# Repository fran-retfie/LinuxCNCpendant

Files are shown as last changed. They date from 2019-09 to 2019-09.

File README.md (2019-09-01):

# LinuxCNC Pendant

This is a pendant for linuxCNC using an SparkFun SAMD21 Dev Breakout but with little or no changes to the program you can run this on other arduino UNO style board.

## Getting Started

**warning** this project may require some changes to make it work properly with your hardware

The project is divided in 4 directories:
* model - a FreeCAD project of the enclosure and a G-code for cutting it
* PCB - a kicad project of the PCB
* Arduino
* Python

### Prerequisites

I suggest you check the PCB before starting beacause there will be maybe some issues: (eg: spacings, SMD parts filipped, ecc..)

for running python program you need the following packages:
* linuxCNC
* TkInter
* tk-tools
* pyserial

### Installing

Upload arduino 'remoteCNC' project on the board and run the python 'remoteCNC' program on a PC with linuxCNC running

## Running the tests

To check pushbuttons and analog input use the 'remoteCNC_test' program on both arduino and PC side.

## Contributing

This project expecially the software in not completed so you are free to contribuite in any way you want.

## Authors

* **Francesco Osti** - *Initial work* - [fran-retfie](https://github.com/fran-retfie)

See also the list of [contributors](https://github.com/fran-retfie/LinuxCNCpendant/contributors)

## License

This project is licensed under the MIT License - see the [LICENSE.md](LICENSE.md) file for details

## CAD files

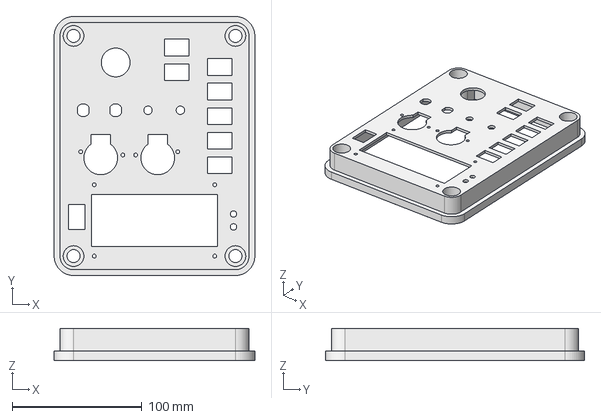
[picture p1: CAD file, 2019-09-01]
model/Test1.FCStd
155.0 x 200.0 x 25.0 mm

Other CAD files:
model/PathCoperchio.FCStd

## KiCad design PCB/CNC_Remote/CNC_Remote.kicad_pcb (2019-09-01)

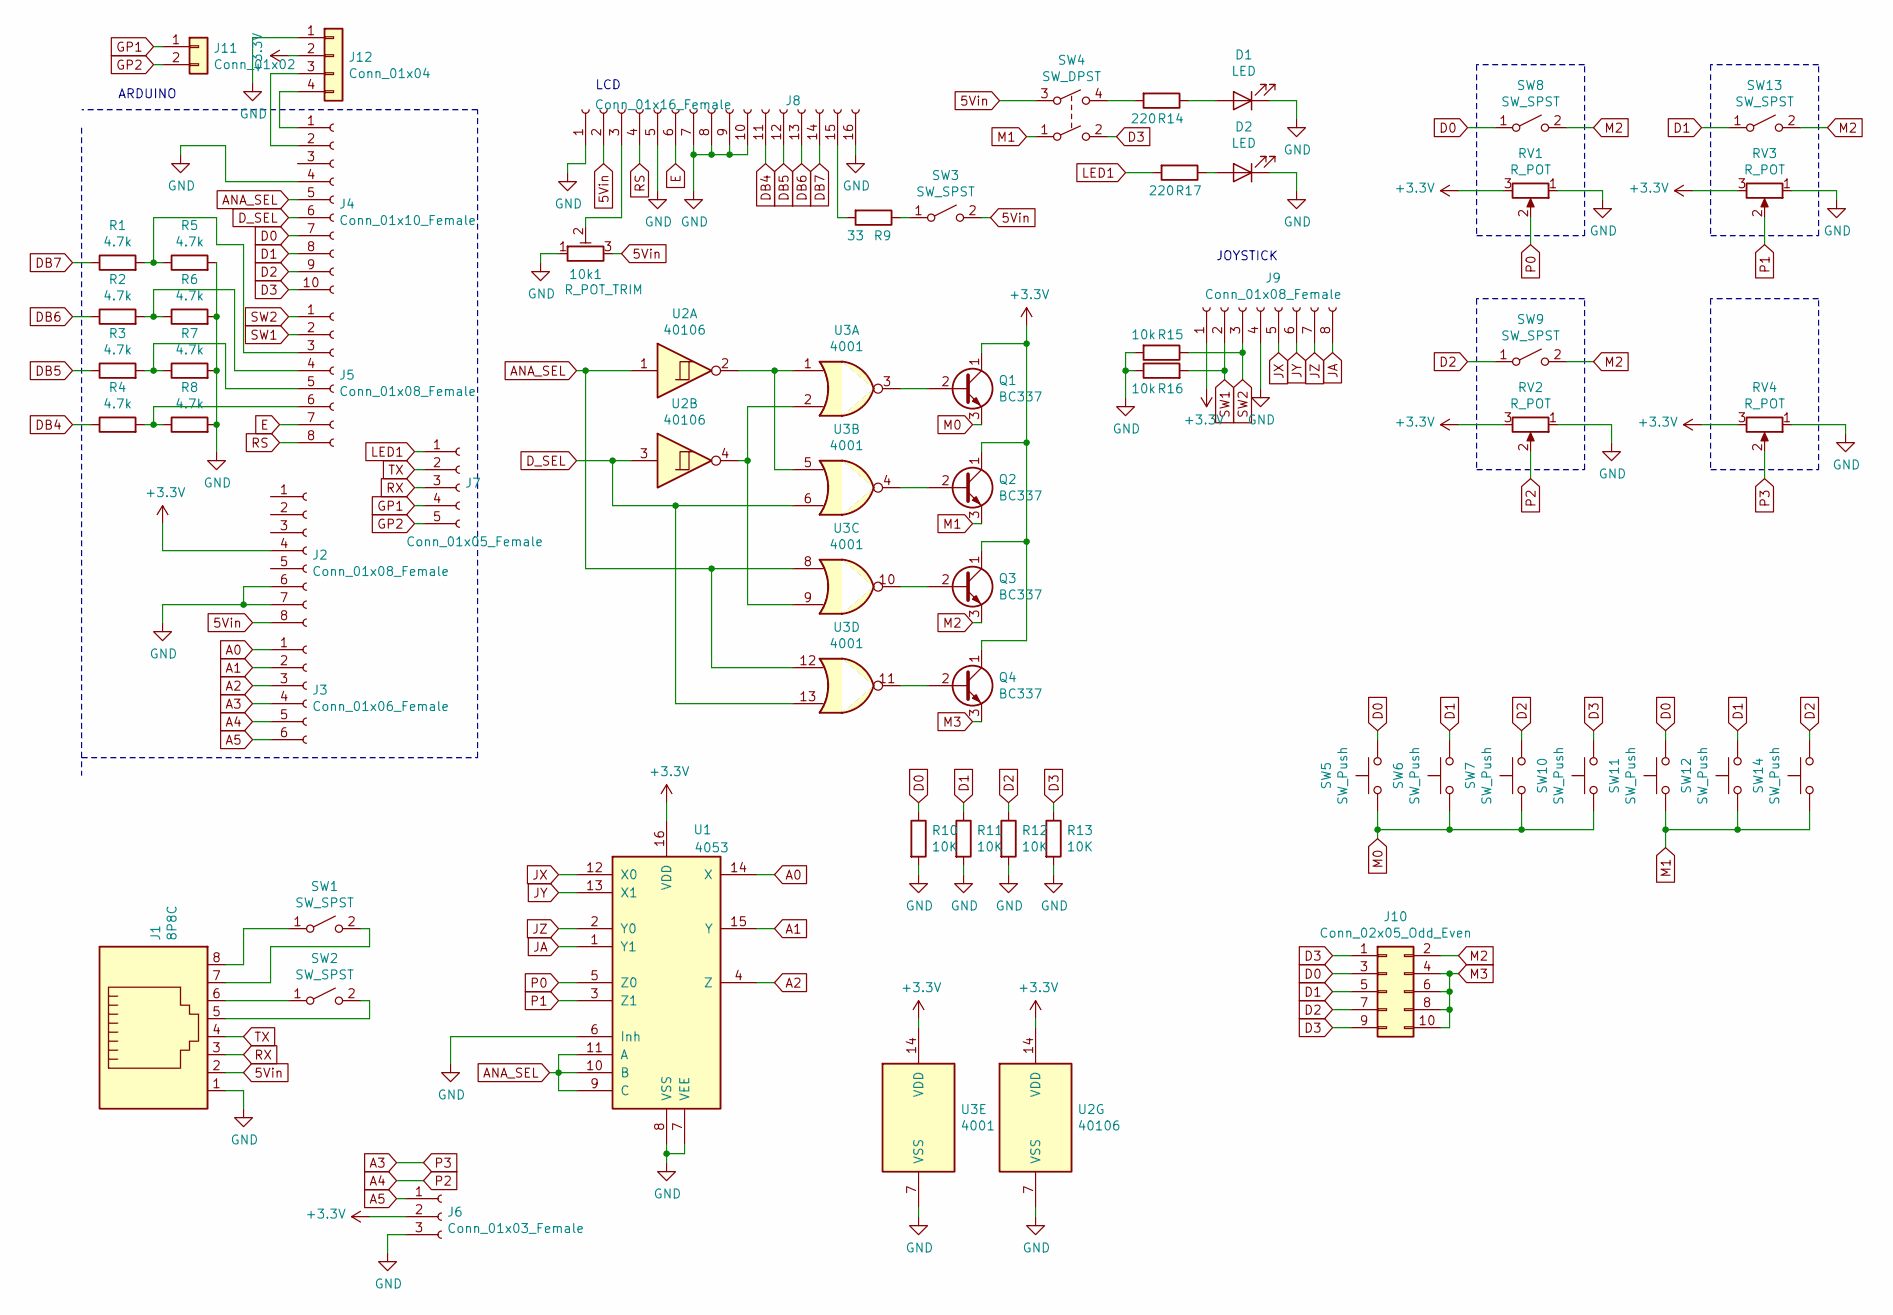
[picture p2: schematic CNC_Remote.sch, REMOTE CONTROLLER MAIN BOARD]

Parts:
10k1: R_POT_TRIM; Potentiometer_Piher_PT-10-V10_Vertical
D1, D2: LED; PinHeader_1x02_P2.54mm_Vertical
J1: 8P8C; RJ45_Amphenol_54602-x08_Horizontal
J2, J5, J9: Conn_01x08_Female; PinHeader_1x08_P2.54mm_Vertical
J3: Conn_01x06_Female; PinHeader_1x06_P2.54mm_Vertical
J4: Conn_01x10_Female; PinHeader_1x10_P2.54mm_Vertical
J6: Conn_01x03_Female; PinHeader_1x03_P2.54mm_Vertical
J7: Conn_01x05_Female; PinHeader_1x05_P2.54mm_Vertical
J8: Conn_01x16_Female; PinHeader_1x16_P2.54mm_Vertical
J10: Conn_02x05_Odd_Even; PinHeader_2x05_P2.54mm_Horizontal
J11: Conn_01x02; PinHeader_1x02_P2.54mm_Vertical
J12: Conn_01x04; PinHeader_1x04_P2.54mm_Vertical
Q1, Q2, Q3, Q4: BC337; TO-92_Inline
R1, R2, R3, R4, R5, R6, R7, R8: 4.7k; R_Axial_DIN0207_L6.3mm_D2.5mm_P10.16mm_Horizontal
R9: 33; R_Axial_DIN0207_L6.3mm_D2.5mm_P10.16mm_Horizontal
R10, R11, R12, R13: 10K; R_Axial_DIN0207_L6.3mm_D2.5mm_P10.16mm_Horizontal
R14, R17: 220; R_Axial_DIN0207_L6.3mm_D2.5mm_P10.16mm_Horizontal
R15, R16: 10k; R_Axial_DIN0207_L6.3mm_D2.5mm_P10.16mm_Horizontal
RV1, RV2, RV3, RV4: R_POT; PinHeader_1x03_P2.54mm_Vertical
SW1, SW2, SW3, SW8, SW9, SW13: SW_SPST; PinHeader_1x02_P2.54mm_Vertical
SW4: SW_DPST; PinHeader_1x04_P2.54mm_Vertical
SW5, SW6, SW7, SW10, SW11, SW12, SW14: SW_Push; PinHeader_1x02_P2.54mm_Vertical
U1: 4053; SOIC-16W_5.3x10.2mm_P1.27mm
U2: 40106; DIP-14_W7.62mm_Socket_LongPads
U3: 4001; DIP-14_W7.62mm_Socket_LongPads

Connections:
5Vin: 10k1.3, J1.2, J2.8, J8.2, SW3.2 (B), SW4.3
+3V3: J2.4, J6.2, J9.1, J12.2, Q1.1 (C), Q2.1 (C), Q3.1 (C), Q4.1 (C), RV1.3, RV2.3, RV3.3, RV4.3, U1.16 (VDD), U2.14 (VDD), U3.14 (VDD)
A0: J3.1, U1.14 (X)
A1: J3.2, U1.15 (Y)
A2: J3.3, U1.4 (Z)
A3: J3.4, RV4.2
A4: J3.5, RV2.2
A5: J3.6, J6.1
ANA_SEL: J4.5, U1.9 (C), U1.10 (B), U1.11 (A), U2.1, U3.8, U3.12
D0: J4.7, J10.3, R10.1, SW5.2, SW8.1 (A), SW11.2
D1: J4.8, J10.5, R11.1, SW6.2, SW12.2, SW13.1 (A)
D2: J4.9, J10.7, R12.1, SW7.2, SW9.1 (A), SW14.2
D3: J4.10, J10.1, J10.9, R13.1, SW4.2, SW10.2
DB4: J8.11, R4.1
DB5: J8.12, R3.1
DB6: J8.13, R2.1
DB7: J8.14, R1.1
D_SEL: J4.6, U2.3, U3.6, U3.13
E: J5.7, J8.6
GND: 10k1.1, D1.1 (K), D2.1 (K), J1.1, J2.6, J2.7, J4.4, J6.3, J8.1, J8.5, J8.7, J8.8, J8.9, J8.10, J8.16, J9.4, J12.1, R5.2, R6.2, R7.2, R8.2, R10.2, R11.2, R12.2, R13.2, R15.2, R16.1, RV1.1, RV2.1, RV3.1, RV4.1, U1.6 (Inh), U1.7 (VEE), U1.8 (VSS), U2.7 (VSS), U3.7 (VSS)
GP1: J7.4, J11.1
GP2: J7.5, J11.2
JA: J9.8, U1.1 (Y1)
JX: J9.5, U1.12 (X0)
JY: J9.6, U1.13 (X1)
JZ: J9.7, U1.2 (Y0)
LED1: J7.1, R17.2
M0: Q1.3 (E), SW5.1, SW6.1, SW7.1, SW10.1
M1: Q2.3 (E), SW4.1, SW11.1, SW12.1, SW14.1
M2: J10.2, Q3.3 (E), SW8.2 (B), SW9.2 (B), SW13.2 (B)
M3: J10.4, J10.6, J10.8, J10.10, Q4.3 (E)
unnamed: 10k1.2, J8.3
unnamed: D1.2 (A), R14.1
unnamed: D2.2 (A), R17.1
unnamed: J1.5, SW2.2 (B)
unnamed: J1.6, SW2.1 (A)
unnamed: J1.7, SW1.2 (B)
unnamed: J1.8, SW1.1 (A)
unnamed: J5.3, R1.2, R5.1
unnamed: J5.4, R2.2, R6.1
unnamed: J5.5, R3.2, R7.1
unnamed: J5.6, R4.2, R8.1
unnamed: J8.15, R9.2
unnamed: J4.2, J12.3
unnamed: J4.1, J12.4
unnamed: Q1.2 (B), U3.3
unnamed: Q2.2 (B), U3.4
unnamed: Q3.2 (B), U3.10
unnamed: Q4.2 (B), U3.11
unnamed: R9.1, SW3.1 (A)
unnamed: R14.2, SW4.4
unnamed: U2.2, U3.1, U3.5
unnamed: U2.4, U3.2, U3.9
P0: RV1.2, U1.5 (Z0)
P1: RV3.2, U1.3 (Z1)
RS: J5.8, J8.4
RX: J1.3, J7.3
SW1: J5.2, J9.2, R16.2
SW2: J5.1, J9.3, R15.1
TX: J1.4, J7.2

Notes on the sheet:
ARDUINO
LCD
JOYSTICK

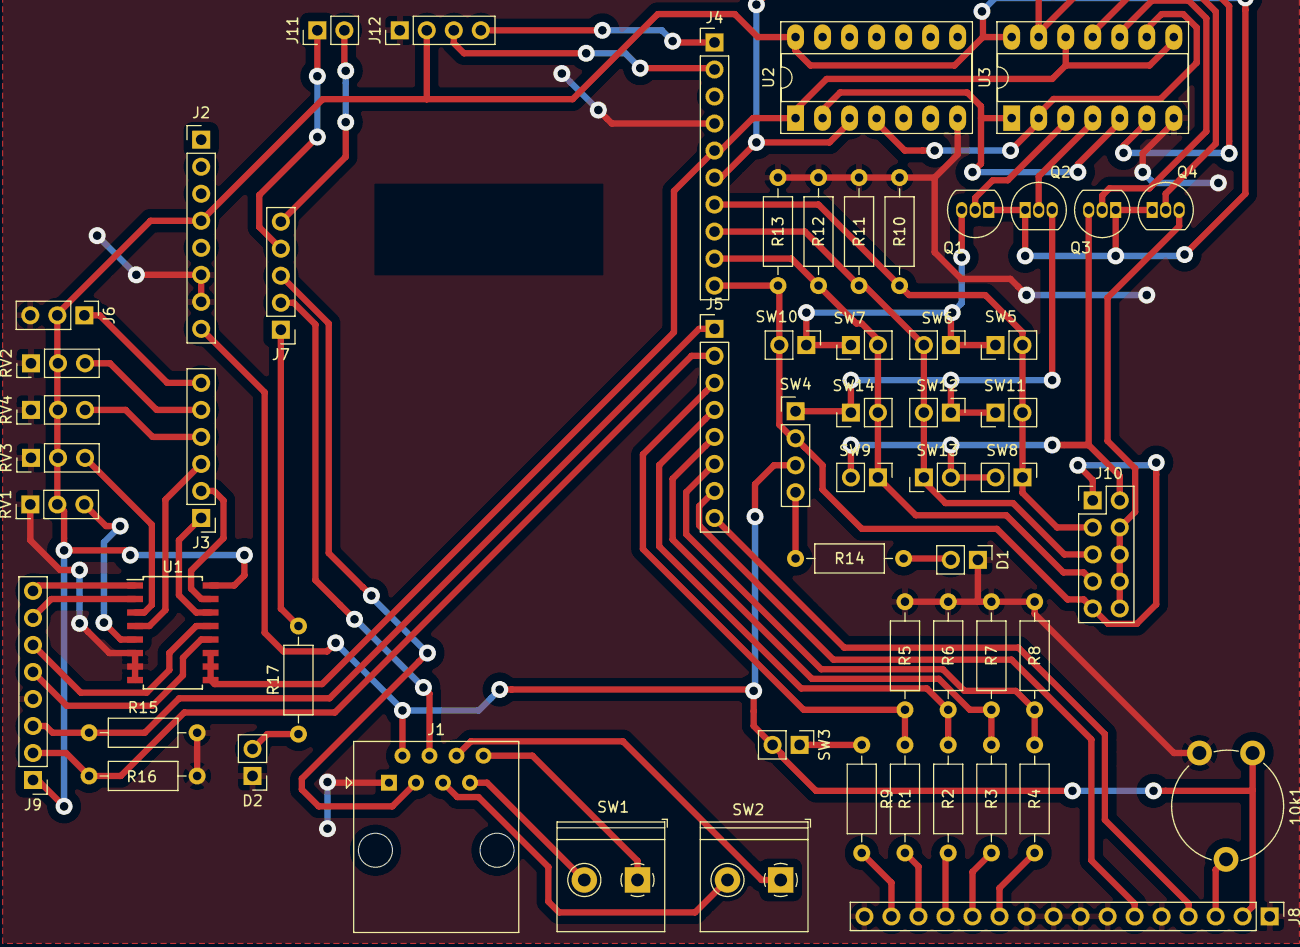
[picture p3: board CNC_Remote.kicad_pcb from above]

Board: 2 copper layers, 57 parts (0 on the bottom side), 60 nets.

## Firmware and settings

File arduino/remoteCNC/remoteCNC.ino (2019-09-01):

#include <LiquidCrystal.h>


const int rs = 0, en = 1, d4 = 2, d5 = 3, d6 = 4, d7 = 5;
const int sw1 = 6, sw2 = 7;
const int D3 = 8, D2 = 9, D1 = 10,  D0 = 11, D_SEL = 12, ANA_SEL = 13;
const int LED = 38;

LiquidCrystal lcd(rs, en, d4, d5, d6, d7);

void SendInt(int val);

unsigned char SelFlag = 0x00;
void writeSel();

unsigned int Contacts = 0x0000;
unsigned int oldContacts = 0x0000;
unsigned int posedgeContacts = 0x0000;
unsigned int negedgeContacts = 0x0000;
unsigned char JogButtons = 0x00;
void readContacts();

int Pot0 = 0x0000;
int Pot1 = 0x0000;
int Pot2 = 0x0000;
int Pot3 = 0x0000;
int JogX = 0x0000;
int JogY = 0x0000;
int JogZ = 0x0000;
int JogA = 0x0000;
void readAnalog();


int Pot0old = 0x0000;
int Pot1old = 0x0000;
int Pot2old = 0x0000;
int Pot3old = 0x0000;

float posX = 0;
float posY = 0;
float posZ = 0;

void SendData();

const int WarnTIME = 1000;
const int LedTIME = 70;
unsigned char MenuFlag = 0x00;
int MenuTimer = 0;

const int DebounceTime = 10;
int DebounceTimer = 0;

const int JogTime = 10;
int JogTimer = 0;


void PrintMode();
void PrintPosition();

void ChangeMode();
void Start();
void Stop();
void Step();
void Pause();
void Flood();
void ON();
void OFF();
void EnableJOG();
void DisableJOG();
void Dummy();

typedef void (* GenericFP)(void);
GenericFP PressEvents[16] = {Dummy, Dummy, Dummy, Dummy, Dummy, Dummy, Pause, Dummy, Flood, Dummy, EnableJOG, ON, Start, ChangeMode, Stop, Step};
GenericFP RelaseEvents[16] = {Dummy, Dummy, Dummy, Dummy, Dummy, Dummy, Dummy, Dummy, Dummy, Dummy, DisableJOG, OFF, Dummy, Dummy, Dummy, Dummy};


void setup() 
{
  analogReadResolution(12);

  pinMode(sw1, INPUT);
  pinMode(sw2, INPUT);
  pinMode(D0, INPUT);
  pinMode(D1, INPUT);
  pinMode(D2, INPUT);
  pinMode(D3, INPUT);
  pinMode(D_SEL, OUTPUT);
  pinMode(ANA_SEL, OUTPUT);
  
  pinMode(LED, OUTPUT);

  SerialUSB.begin(115200, SERIAL_8E1);

  lcd.begin(20, 4); 
  LCD_progress_bar_init();

  lcd.setCursor (0, 0);
  lcd.print("CNC pendant v1.0");
  lcd.setCursor (0, 1);
  lcd.print("have a good day and");
  lcd.setCursor (0, 2);
  lcd.print("I hope you don't ");
  lcd.setCursor (0, 3);
  lcd.print("break any endmill");
}

void loop() 
{ 
  readContacts();
  readAnalog();
  writeSel();


  DebounceTimer++;
  if(DebounceTimer > DebounceTime)
  {
    DebounceTimer = 0;
    
    posedgeContacts = Contacts & ~oldContacts;
    negedgeContacts = ~Contacts & oldContacts;
    oldContacts = Contacts;

    for(unsigned char i = 0; i<16; i++)
    {
      if(posedgeContacts & (0x01<<i)) (*PressEvents[i]) ();
      if(negedgeContacts & (0x01<<i)) (*RelaseEvents[i]) ();
    }

    if(abs(Pot0 - Pot0old)>20)
    {
      SerialUSB.write('0');
      SendInt(Pot0);
      Pot0old = Pot0;
    }

    if(abs(Pot1 - Pot1old)>20)
    {
      SerialUSB.write('1');
      SendInt(Pot1);
      Pot1old = Pot1;
    }

    if(abs(Pot2 - Pot2old)>20)
    {
      SerialUSB.write('2');
      SendInt(Pot2);
      Pot2old = Pot2;
    }

    if((abs(Pot3 - Pot3old)>20) && (MenuFlag & 0x08))
    {
      SerialUSB.write('3');
      SendInt(4096 - Pot3);
      Pot3old = Pot3;
    }

  }
  
  PrintMode();
  
  if(SerialUSB.available() > 0)
  {
    switch(SerialUSB.read())
    {
      case 'A':
        if((MenuFlag && 0x03) != 0x02)  PrintMode();
        MenuFlag &= ~(0x2B);
        MenuFlag |= 0x02;
        PrintPosition();
      break;

      case 'M':
        if((MenuFlag && 0x03) != 0x00)  PrintMode();
        MenuFlag &= ~(0x2B);
        MenuFlag |= 0x00;
        PrintPosition();
      break;

      case 'J':
        if((MenuFlag && 0x03) != 0x01)  PrintMode();
        MenuFlag &= ~(0x23);
        MenuFlag |= 0x01;
        PrintPosition();
      break;

      case 'I':
        char inStr[21];
        SerialUSB.readBytes(inStr, 20);
        inStr[20] = 0x00;
        MenuTimer = 0;
        lcd.setCursor (0, 0);
        lcd.print(inStr);
      break;

      case 'R':
        if(MenuFlag && 0x08)
        {
          SerialUSB.write('R');
          SendInt(JogX);
          SendInt(JogY);
          SendInt(JogZ);
          SendInt(JogA);
        } 
      break;

      default:
      break;
    }
  }

  delay(1);
}




void SendData()
{
    SerialUSB.write(0x55);
    SerialUSB.write(JogButtons);
    SendInt(Contacts);
    SendInt(Pot0);
    SendInt(Pot1);
    SendInt(Pot2);
    SendInt(Pot3);
    SendInt(JogX);
    SendInt(JogY);
    SendInt(JogZ);
    SendInt(JogA);
}












//

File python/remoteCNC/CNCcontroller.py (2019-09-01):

import sys
sys.path.append('/home/retfie/linuxcnc-dev/lib/python/')


import serial
import time
import struct
import linuxcnc
import decodeData as dD
import CNCcommands as Cc

PORT = "/dev/ttyACM0"
ser = serial.Serial(PORT, baudrate = 115200, parity = serial.PARITY_EVEN, stopbits = serial.STOPBITS_ONE, timeout=0.5, write_timeout = 0)

try:
        s = linuxcnc.stat() # create a connection to the status channel
        s.poll() # get current values
        c = linuxcnc.command()
        print("connected to linuxcnc")
except (linuxcnc.error):
        print("unable to connect to linuxcnc")
        sys.exit(1)

Cc.sendInfo(ser,"connected to CNC")

actions = {'S' : Cc.Start, 'T' : Cc.Stop, 'A' : Cc.AUTOmode, 'M' : Cc.MDImode, 'G' : Cc.JOGmode, 'P' : Cc.Step, 'E' : Cc.Pause, 'F' : Cc.FloodON, 'f' : Cc.FloodOFF, 'O' : Cc.ON, 'o' : Cc.OFF, 'J' : Cc.JOGon,  'j' : Cc.JOGoff, 'R' : Cc.JOG, '1' : Cc.FeedSpeedSet, '0' : Cc.RapidSpeedSet, '2' : Cc.MaxSpeedSet, '3' : Cc.JOGspeedSet}

def dummyEvent(s,c,d):
    pass

t = time.time()

while 1:

    if (ser.inWaiting() > 0):
        InCMD = (ser.read(size = 1)).decode()
        if (InCMD != 'J'):
            Cc.haltJog(c);
        actions.get(InCMD,dummyEvent)(c,ser,s)

    if(time.time() - t > 0.2):
        s.poll()
        pos = s.actual_position
        mode = s.task_mode
        state = s.enabled
        #state = s.task_state

        modeChar = { linuxcnc.MODE_MDI : 'M', linuxcnc.MODE_AUTO : 'A', linuxcnc.MODE_MANUAL : 'J'}
        #stateChar = { linuxcnc.STATE_ESTOP : 'E', linuxcnc.STATE_ESTOP_RESET : 'R', linuxcnc.STATE_ON : 'O', linuxcnc.STATE_OFF : 'F'}

        if state:
            stateChar = 'O'
        else:
            stateChar = 'F'

        posX = "{:6.3f}".format(pos[0])
        posY = "{:6.3f}".format(pos[1])
        posZ = "{:6.3f}".format(pos[2])
        posStr = modeChar[mode] + stateChar + "X:" + posX + " "*(18-len(posX)) + "Y:" + posY + " "*(18-len(posY)) + "Z:" + posZ + " "*(18-len(posZ)) + "e"
        ser.write(posStr.encode())
        t = time.time()

    Cc.JOGinputRequest(ser)
